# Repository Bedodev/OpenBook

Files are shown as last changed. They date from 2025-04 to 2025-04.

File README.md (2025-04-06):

# OpenBook
OpenBook is an open Source eBook Project that aims to create a simple yet powerful esp32-based ebook reader, with quality of life features. 

## Block Diagram
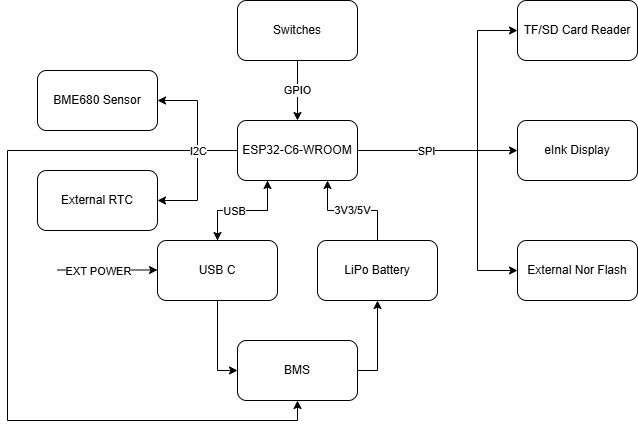
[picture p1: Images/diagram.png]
block-diagram


## Simplified BoM
Component | Part # | Source Link
--- | --- | ---
ESP32 | ESP32-C6-WROOM-1-N8 | [Mouser](https://mou.sr/42swLfH)
MicroSD Card Reader | 112A-TAAR-R03 | [DigiKey](https://www.digikey.ro/en/models/17633923)
NOR Flash | W25Q512JVEIQ | [ComponentSearchengine](https://componentsearchengine.com/search?term=W25Q512JVEIQ)
Adafruit Led | SM0603UYC | [SnapEda](https://www.snapeda.com/parts/SM0603UYC/Bivar/view-part/)
Environment Sensor | BME680 | [DigiKey](https://www.digikey.lt/en/models/7401317)
Super Capacitor | CPH3225A-2K | [SnapMagic](https://www.snapeda.com/parts/CPH3225A-2K/Seiko/view-part/)
0402 capsule | RC0402 | [GrabCad](https://grabcad.com/library/tag/0402)
Tantalum Capacitor | TR3B106K025C1300 | [Mouser](https://eu.mouser.com/ProductDetail/Vishay-Sprague/TR3B106K025C1300?qs=jCGqFXxTmLdffnuDkXzk1g%3D%3D)
RTC | DS3231SN# | [ComponentSearchEngine](https://componentsearchengine.com/part-view/DS3231SN%23/Analog%20Devices)
Voltage Detector | BD5229G-TR | [ComponentSearchEngine](https://componentsearchengine.com/part-view/BD5229G-TR/ROHM%20Semiconductor)
Right Angle Switches | EVQ-P7M01P | [Mouser](https://mou.sr/41Z13GK)
Inductor | 784373170680 | [DigiKey](https://www.digikey.ro/en/models/1638502)
Varsistor | CT1812K50G | [ComponentSearchEngine](https://componentsearchengine.com/part-view/CT1812K50G/TDK)
Schottky Diode | SD0805S020S1R0 | [ComponentSearchEngine](https://componentsearchengine.com/part-view/SD0805S020S1R0/Kyocera%20AVX)
Schotty Rectifier | MBR0530 | [ComponentSearchEngine](https://componentsearchengine.com/part-view/MBR0530/onsemi)
ESD Protection | USBLC6-2SC6Y | [ComponentSearchEngine](https://componentsearchengine.com/part-view/USBLC6-2SC6Y/STMicroelectronics)
ESD Suppressors | PGB1010603MR | [ComponentSearchEngine](https://componentsearchengine.com/part-view/PGB1010603MR/LITTELFUSE)
N-MOSFET | Si1308EDL-T1-GE3 | [ComponentSearchEngine](https://componentsearchengine.com/part-view/SI1308EDL-T1-GE3/Vishay)
Qwiic Connector | PRT-14417 | [ComponentSearchEngine](https://componentsearchengine.com/part-view/PRT-14417/SparkFun)
USB Connector | USB4110-GF-A | [ComponentSearchEngine](https://componentsearchengine.com/part-view/USB4110-GF-A/GCT%20(GLOBAL%20CONNECTOR%20TECHNOLOGY))
Display Connector | FH34SRJ-24S-0.5SH(99) | [ComponentSearchEngine](https://componentsearchengine.com/part-view/FH34SRJ-24S-0.5SH(99)/Hirose)
Battery Percentage Chip | MAX17048G+T10 | [ComponentSearchEngine](https://componentsearchengine.com/part-view/MAX17048G%2BT10/Analog%20Devices)
Voltage Reculator | XC6220A331MR-G | [ComponentSearchEngine](https://componentsearchengine.com/part-view/XC6220A331MR-G/Torex)
LiPo Controller | HT7750A | [ComponentSearchengine](https://componentsearchengine.com/part-view/HT7750A%20SOT23-3/Holtek)

## Hardware Overview
  -  **ESP32-C6**: energy efficient RISC based mcu, with wireless connectivity for easy ebook content access and transfer
  -  **eInk Display**: energy efficient black and white display with paper-like look
  -  **Usb-C Port**: easy charging and connectivity with esd protection
  -  **SdCard Reader**: user-accessible expandable storage
  -  **External Flash**: built-in storage for basic functionality
  -  **Real Time Clock**: maintains time data on power off
  -  **Environmental Sensor**: high-accuracy environment data collection for safe usage warnings
  -  **Qwiic Connector**: allows future expandability
  -  **Side Switches**: simple user interfacing with device operations

## ESP32 Pin Mapping
 1. **USB**: user charging and data access
    - IO12 - Usb Data-
    - IO13 - Usb Data+
 2. **GPIO**: user interfacing
    - EN - reset switch, for easy access to chip reset
    - IO9 - "change" switch, for display mode switch
    - IO15 - boot switch, for device startup and shutdown
 2. **SPI**: display, sd card, flash
    - IO2 - MISO, master in slave out, used for data transfer from chip to esp
    - IO7 - MOSI, master out slave in, used for data transfer from esp to chip
    - IO6 - SCK, clock bus sync between esp and chip
    - IO5 - DC, data/command
    - IO3 - busy, for signaling device cannot receive command
 2. **I2C**: battery monitoring, rtc, environment sensing
    - IO21 - SDA, bidirectional serial data line
    - IO22 - SCL, bidirectional serial clock line

## Other comments
 - DRC warnings for the usb allignment pins have to be manually approved
 - Inductor 3D model different from BoM component, but, for development and showcase purposes, footprint and 3D model fit the original

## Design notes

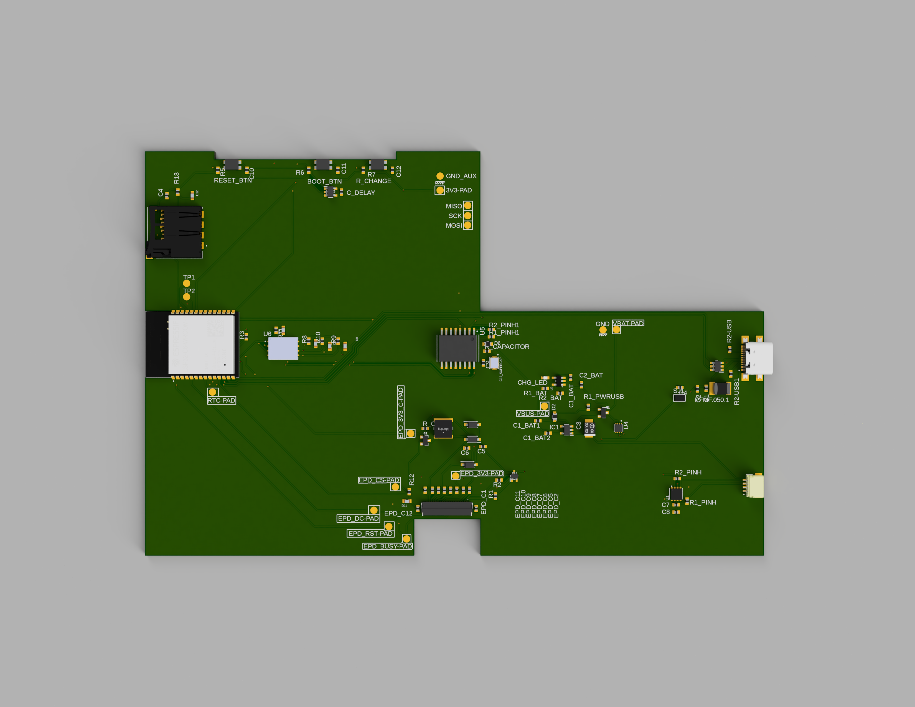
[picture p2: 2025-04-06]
Images/pcb_3d_front.png

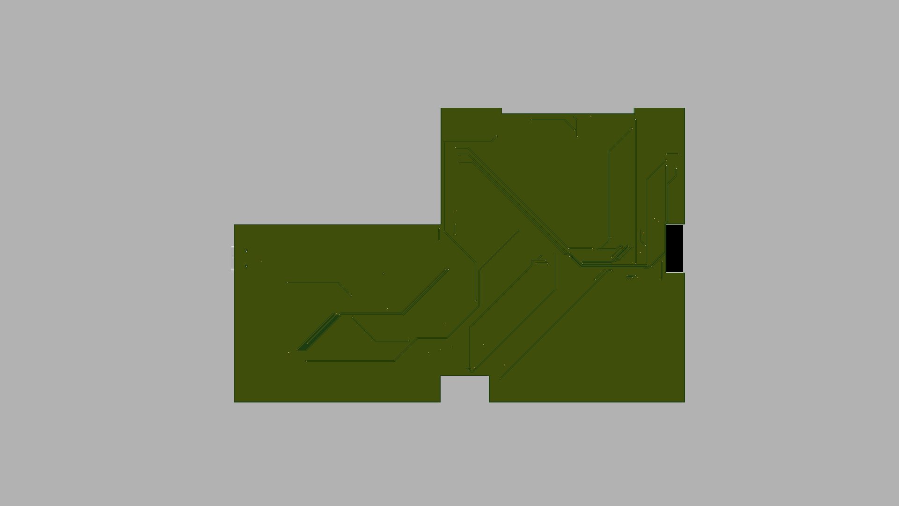
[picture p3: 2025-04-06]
Images/pcb_3d_back.png

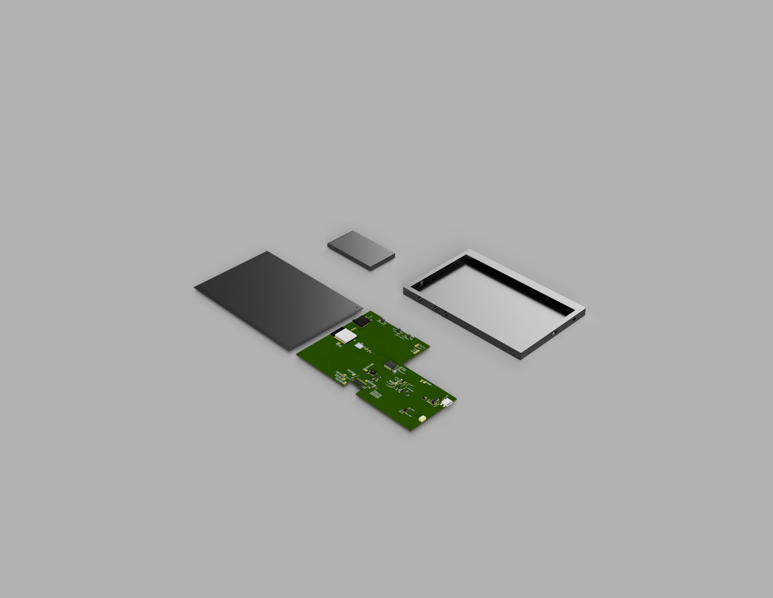
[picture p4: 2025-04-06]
Images/exploded_flat.png

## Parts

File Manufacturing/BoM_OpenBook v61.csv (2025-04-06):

Part | Value | Device | Package | Description
3V3-PAD | TPTP20R | TPTP20R | TP20R | Test pad
BOOT_BTN | BUTTON_CUSYOMV1 | BUTTON_CUSYOMV1 | MYBUTTON
C1 | 100nF | ESP32_WROVER_EAGLE-LTSPICE_CC0402 | ESP32_WROVER_EAGLE-LTSPICE_C0402 | CAPACITOR, European symbol
C1_BAT | 4.7uF | EAGLE-LTSPICE_CC0402 | EAGLE-LTSPICE_C0402 | CAPACITOR, European symbol
C1_BAT1 | 4.7uF | EAGLE-LTSPICE_CC0402 | EAGLE-LTSPICE_C0402 | CAPACITOR, European symbol
C1_BAT2 | 4.7uF | EAGLE-LTSPICE_CC0402 | EAGLE-LTSPICE_C0402 | CAPACITOR, European symbol
C2 | 100nF | ESP32_WROVER_EAGLE-LTSPICE_CC0402 | ESP32_WROVER_EAGLE-LTSPICE_C0402 | CAPACITOR, European symbol
C2_BAT | 4.7uF | EAGLE-LTSPICE_CC0402 | EAGLE-LTSPICE_C0402 | CAPACITOR, European symbol
C3 | 100uF TANT | RCL_CPOL-EUCT3528 | RCL_CT3528 | POLARIZED CAPACITOR, European symbol
C4 | 100nF | EAGLE-LTSPICE_CC0402 | EAGLE-LTSPICE_C0402 | CAPACITOR, European symbol
C5 | 4.7uF/25V | ESP32_WROVER_EAGLE-LTSPICE_CC0402 | ESP32_WROVER_EAGLE-LTSPICE_C0402 | CAPACITOR, European symbol
C6 | 10uF | ESP32_WROVER_EAGLE-LTSPICE_CC0402 | ESP32_WROVER_EAGLE-LTSPICE_C0402 | CAPACITOR, European symbol
C7 | 100nF | EAGLE-LTSPICE_CC0402 | EAGLE-LTSPICE_C0402 | CAPACITOR, European symbol
C8 | 100nF | EAGLE-LTSPICE_CC0402 | EAGLE-LTSPICE_C0402 | CAPACITOR, European symbol
C9 | 100nF | EAGLE-LTSPICE_CC0402 | EAGLE-LTSPICE_C0402 | CAPACITOR, European symbol
C10 | 1uF | EAGLE-LTSPICE_CC0402 | EAGLE-LTSPICE_C0402 | CAPACITOR, European symbol
C11 | 100nF | EAGLE-LTSPICE_CC0402 | EAGLE-LTSPICE_C0402 | CAPACITOR, European symbol
C12 | 100nF | EAGLE-LTSPICE_CC0402 | EAGLE-LTSPICE_C0402 | CAPACITOR, European symbol
C13_SUPERCAP | CPH3225A | CPH3225A | CAPCP3225X100N | Cap 0.011F 3.3V 1210 Flat Check availability
CHG_LED |  | ADAFRUIT_LEDCHIP-LED0603 | ADAFRUIT_CHIP-LED0603 | LED
C_DELAY | 100nF | EAGLE-LTSPICE_CC0402 | EAGLE-LTSPICE_C0402 | CAPACITOR, European symbol
D1 | USBLC6-2SC6Y | USBLC6-2SC6Y | SOT95P280X145-6N | Low Cap. ESD Protection Auto SOT-23-6 STMicroelectronics USBLC6-2SC6Y, Dual Uni-Directional TVS Diode Array, 6-Pin SOT-23
D2 | ESP32_WROVER_AVX---SD0805S020S1R0_AVX_SD0805S020S1R0_0_0AVX_SD0805S020S1R0_0_0 | ESP32_WROVER_AVX---SD0805S020S1R0_AVX_SD0805S020S1R0_0_0AVX_SD0805S020S1R0_0_0 | ESP32_WROVER_AVX---SD0805S020S1R0_AVX_SD0805S020S1R0_0 | Schottky Barrier Rectifier Diode
D3 | MBR0530 | MBR0530 | SOD3716X135N | ON SEMICONDUCTOR - MBR0530 - DIODE, SCHOTTKY, 0.5A, 30V, SOD-123
D4 | MBR0530 | MBR0530 | SOD3716X135N | ON SEMICONDUCTOR - MBR0530 - DIODE, SCHOTTKY, 0.5A, 30V, SOD-123
D5 | MBR0530 | MBR0530 | SOD3716X135N | ON SEMICONDUCTOR - MBR0530 - DIODE, SCHOTTKY, 0.5A, 30V, SOD-123
D6 | ESP32_WROVER_AVX---SD0805S020S1R0_AVX_SD0805S020S1R0_0_0AVX_SD0805S020S1R0_0_0 | ESP32_WROVER_AVX---SD0805S020S1R0_AVX_SD0805S020S1R0_0_0AVX_SD0805S020S1R0_0_0 | ESP32_WROVER_AVX---SD0805S020S1R0_AVX_SD0805S020S1R0_0 | Schottky Barrier Rectifier Diode
D7 | PGB1010603MR | PGB1010603MR | DIOC1608X36N | Check availability
D8 | PGB1010603MR | PGB1010603MR | DIOC1608X36N | Check availability
D9 | PGB1010603MR | PGB1010603MR | DIOC1608X36N | Check availability
D10 | PGB1010603MR | PGB1010603MR | DIOC1608X36N | Check availability
D11 | PGB1010603MR | PGB1010603MR | DIOC1608X36N | Check availability
D12 | PGB1010603MR | PGB1010603MR | DIOC1608X36N | Check availability
EPD_3V3-PAD | TPTP20R | TPTP20R | TP20R | Test pad
EPD_3V3_C-PAD | TPTP20R | TPTP20R | TP20R | Test pad
EPD_BUSY-PAD | TPTP20R | TPTP20R | TP20R | Test pad
EPD_C1 | 1uF/50V | ESP32_WROVER_EAGLE-LTSPICE_CC0402 | ESP32_WROVER_EAGLE-LTSPICE_C0402 | CAPACITOR, European symbol
EPD_C2 | 1uF/50V | ESP32_WROVER_EAGLE-LTSPICE_CC0402 | ESP32_WROVER_EAGLE-LTSPICE_C0402 | CAPACITOR, European symbol
EPD_C5 | 0.1uF/50V | ESP32_WROVER_EAGLE-LTSPICE_CC0402 | ESP32_WROVER_EAGLE-LTSPICE_C0402 | CAPACITOR, European symbol
EPD_C6 | 1uF/50V | ESP32_WROVER_EAGLE-LTSPICE_CC0402 | ESP32_WROVER_EAGLE-LTSPICE_C0402 | CAPACITOR, European symbol
EPD_C7 | 1uF/50V | ESP32_WROVER_EAGLE-LTSPICE_CC0402 | ESP32_WROVER_EAGLE-LTSPICE_C0402 | CAPACITOR, European symbol
EPD_C8 | 1uF/50V | ESP32_WROVER_EAGLE-LTSPICE_CC0402 | ESP32_WROVER_EAGLE-LTSPICE_C0402 | CAPACITOR, European symbol
EPD_C9 | 1uF/50V | ESP32_WROVER_EAGLE-LTSPICE_CC0402 | ESP32_WROVER_EAGLE-LTSPICE_C0402 | CAPACITOR, European symbol
EPD_C10 | 1uF/50V | ESP32_WROVER_EAGLE-LTSPICE_CC0402 | ESP32_WROVER_EAGLE-LTSPICE_C0402 | CAPACITOR, European symbol
EPD_C11 | 1uF/50V | ESP32_WROVER_EAGLE-LTSPICE_CC0402 | ESP32_WROVER_EAGLE-LTSPICE_C0402 | CAPACITOR, European symbol
EPD_C12 | 1uF/50V | ESP32_WROVER_EAGLE-LTSPICE_CC0402 | ESP32_WROVER_EAGLE-LTSPICE_C0402 | CAPACITOR, European symbol
EPD_CS-PAD | TPTP20R | TPTP20R | TP20R | Test pad
EPD_DC-PAD | TPTP20R | TPTP20R | TP20R | Test pad
EPD_RST-PAD | TPTP20R | TPTP20R | TP20R | Test pad
GND | TPTP20R | TPTP20R | TP20R | Test pad
GND_AUX | TPTP20R | TPTP20R | TP20R | Test pad
IC1 | XC6220A331MR-G | XC6220A331MR-G | SOT95P280X120-5N | LDO Voltage Regulators
IC2 | BD5229G-TR | BD5229G-TR | SOT95P280X125-5N | Voltage Detector with Adjustable Delay Time: CMOS processes are utilized to develop high precision, low current consumption CMOS reset ICs that allow arbitrary setting of the delay time. The extensive lineup includes both Nch Open Drain and CMOS output types in a wide range of detection voltages (from 2.3V to 6.0V, in 0.1V steps), enabling selection of the ideal solution based on customer requirements. In addition, the entire series is of course both lead-free and RoHS-compliant.
J1 | SAMACSYS_PARTS_USB4110-GF-A | SAMACSYS_PARTS_USB4110-GF-A | SAMACSYS_PARTS_USB4110GFA | CONN USB 2.0 TYPE-C R/A SMT
J2 | 112A-TAAR-R03_ATTEND | 112A-TAAR-R03_ATTEND | 112ATAARR03ATTEND | Micro SD Card Socket, Push-Push Type, Top Mount, SMT, H=1.83mm, 10u
J3 | FH34SRJ-24S-0.5SH_99_ | FH34SRJ-24S-0.5SH_99_ | FH34SRJ24S05SH99 | (0.50mm) Surface Mount, Right Angle
J4 | QWIIC_RIGHT_ANGLE | QWIIC_CONNECTORJS-1MM | JST04_1MM_RA | SparkFun I2C Standard Qwiic Connector
L1 | 68uH | 744043680IND_4828-WE-TPC_WRE | IND_4828-WE-TPC_WRE
MISO | TPTP20R | TPTP20R | TP20R | Test pad
MOSI | TPTP20R | TPTP20R | TP20R | Test pad
PFMF.050.1 | PFMF.050.1 | ESP32C6_VARISTORCN1812 | ESP32C6_VARISTOR_CT/CN1812 | VARISTOR
Q1 | 20V/4.2A/52mO/1.4W | ESP32_WROVER_SPARKFUN-DISCRETESEMI_MOSFET_PCH-DMG2305UX-7 | ESP32_WROVER_SPARKFUN-DISCRETESEMI_SOT23-3 | P-channel MOSFETs
Q2 | SI1308EDL-T1-GE3 | SI1308EDL-T1-GE3 | SOT65P210X110-3N | MOSFET N-Ch 30V 1.5A TrenchFET SC70 Vishay Si1308EDL-T1-GE3 N-channel MOSFET Transistor, 1.5 A, 30 V, 3-Pin SC-70
Q3 | 20V/4.2A/52mO/1.4W | ESP32_WROVER_SPARKFUN-DISCRETESEMI_MOSFET_PCH-DMG2305UX-7 | ESP32_WROVER_SPARKFUN-DISCRETESEMI_SOT23-3 | P-channel MOSFETs
R1 | 10K | ESP32_WROVER_EAGLE-LTSPICE_RR0402 | ESP32_WROVER_EAGLE-LTSPICE_R0402 | RESISTOR, European symbol
R1_BAT | 200 | ESP32_WROVER_EAGLE-LTSPICE_RR0402 | ESP32_WROVER_EAGLE-LTSPICE_R0402 | RESISTOR, European symbol
R1_PINH | 10K | ESP32_WROVER_EAGLE-LTSPICE_RR0402 | ESP32_WROVER_EAGLE-LTSPICE_R0402 | RESISTOR, European symbol
R1_PINH1 | 10K | ESP32_WROVER_EAGLE-LTSPICE_RR0402 | ESP32_WROVER_EAGLE-LTSPICE_R0402 | RESISTOR, European symbol
R1_PWRUSB | 100K | ESP32_WROVER_EAGLE-LTSPICE_RR0402 | ESP32_WROVER_EAGLE-LTSPICE_R0402 | RESISTOR, European symbol
R2 | 0.47 | ESP32_WROVER_EAGLE-LTSPICE_RR0402 | ESP32_WROVER_EAGLE-LTSPICE_R0402 | RESISTOR, European symbol
R2-USB | 5k1 | ESP32_WROVER_EAGLE-LTSPICE_RR0402 | ESP32_WROVER_EAGLE-LTSPICE_R0402 | RESISTOR, European symbol
R2-USB1 | 5k1 | ESP32_WROVER_EAGLE-LTSPICE_RR0402 | ESP32_WROVER_EAGLE-LTSPICE_R0402 | RESISTOR, European symbol
R2_BAT | 2K | ESP32_WROVER_EAGLE-LTSPICE_RR0402 | ESP32_WROVER_EAGLE-LTSPICE_R0402 | RESISTOR, European symbol
R2_PINH | 10K | ESP32_WROVER_EAGLE-LTSPICE_RR0402 | ESP32_WROVER_EAGLE-LTSPICE_R0402 | RESISTOR, European symbol
R2_PINH1 | 10K | ESP32_WROVER_EAGLE-LTSPICE_RR0402 | ESP32_WROVER_EAGLE-LTSPICE_R0402 | RESISTOR, European symbol
R3 | 10K | ESP32_WROVER_EAGLE-LTSPICE_RR0402 | ESP32_WROVER_EAGLE-LTSPICE_R0402 | RESISTOR, European symbol
R4 | 2.2 | ESP32_WROVER_EAGLE-LTSPICE_RR0402 | ESP32_WROVER_EAGLE-LTSPICE_R0402 | RESISTOR, European symbol
R5 |  | ESP32_WROVER_EAGLE-LTSPICE_RR0402 | ESP32_WROVER_EAGLE-LTSPICE_R0402 | RESISTOR, European symbol
R6 |  | ESP32_WROVER_EAGLE-LTSPICE_RR0402 | ESP32_WROVER_EAGLE-LTSPICE_R0402 | RESISTOR, European symbol
R7 |  | ESP32_WROVER_EAGLE-LTSPICE_RR0402 | ESP32_WROVER_EAGLE-LTSPICE_R0402 | RESISTOR, European symbol
R8 | 10K | ESP32_WROVER_EAGLE-LTSPICE_RR0402 | ESP32_WROVER_EAGLE-LTSPICE_R0402 | RESISTOR, European symbol
R9 | 10K | ESP32_WROVER_EAGLE-LTSPICE_RR0402 | ESP32_WROVER_EAGLE-LTSPICE_R0402 | RESISTOR, European symbol
R10 | 10K | ESP32_WROVER_EAGLE-LTSPICE_RR0402 | ESP32_WROVER_EAGLE-LTSPICE_R0402 | RESISTOR, European symbol
R11 | 10K | ESP32_WROVER_EAGLE-LTSPICE_RR0402 | ESP32_WROVER_EAGLE-LTSPICE_R0402 | RESISTOR, European symbol
R12 | 10K | ESP32_WROVER_EAGLE-LTSPICE_RR0402 | ESP32_WROVER_EAGLE-LTSPICE_R0402 | RESISTOR, European symbol
R13 | 10K | ESP32_WROVER_EAGLE-LTSPICE_RR0402 | ESP32_WROVER_EAGLE-LTSPICE_R0402 | RESISTOR, European symbol
RESET_BTN | BUTTON_CUSYOMV1 | BUTTON_CUSYOMV1 | MYBUTTON
RTC-PAD | TPTP20R | TPTP20R | TP20R | Test pad
R_CAPACITOR |  | ESP32_WROVER_EAGLE-LTSPICE_RR0402 | ESP32_WROVER_EAGLE-LTSPICE_R0402 | RESISTOR, European symbol
R_CHANGE | BUTTON_CUSYOMV1 | BUTTON_CUSYOMV1 | MYBUTTON
R_CL1 | 10K | ESP32_WROVER_EAGLE-LTSPICE_RR0402 | ESP32_WROVER_EAGLE-LTSPICE_R0402 | RESISTOR, European symbol
SCK | TPTP20R | TPTP20R | TP20R | Test pad
SJ1 |  | SJ | SJ | SMD solder JUMPER
TP1 | TPTP20R | TPTP20R | TP20R | Test pad
TP2 | TPTP20R | TPTP20R | TP20R | Test pad
U1 | BME688 | ESP32_WROVER_BME680_BME680 | ESP32_WROVER_BME680_PSON80P300X300X100-8N | Integrated Environmental Unit
U2 | MCP73831 | ESP32_WROVER_SPARKFUN-IC-POWER_MCP73831 | ESP32_WROVER_SPARKFUN-IC-POWER_SOT23-5 | MCP73831T Li-Ion, Li-Pol Controller
U3 | ESP32-C6-WROOM-1-N8 | ESP32-C6-WROOM-1-N8 | XCVR_ESP32-C6-WROOM-1-N8 | Check availability
U4 | MAX17048G+T10 | MAX17048G+T10 | SON50P200X200X80-9N | Check availability
U5 | DS3231SN# | DS3231SN# | SOIC127P1032X265-16N | Real Time Clock Serial 16-Pin SOIC W T/R Check availability
U6 | W25Q512JVEIQ | W25Q512JVEIQ | SON127P600X800X80-9N | Check availability
VBAT-PAD | TPTP20R | TPTP20R | TP20R | Test pad
VBUS-PAD | TPTP20R | TPTP20R | TP20R | Test pad

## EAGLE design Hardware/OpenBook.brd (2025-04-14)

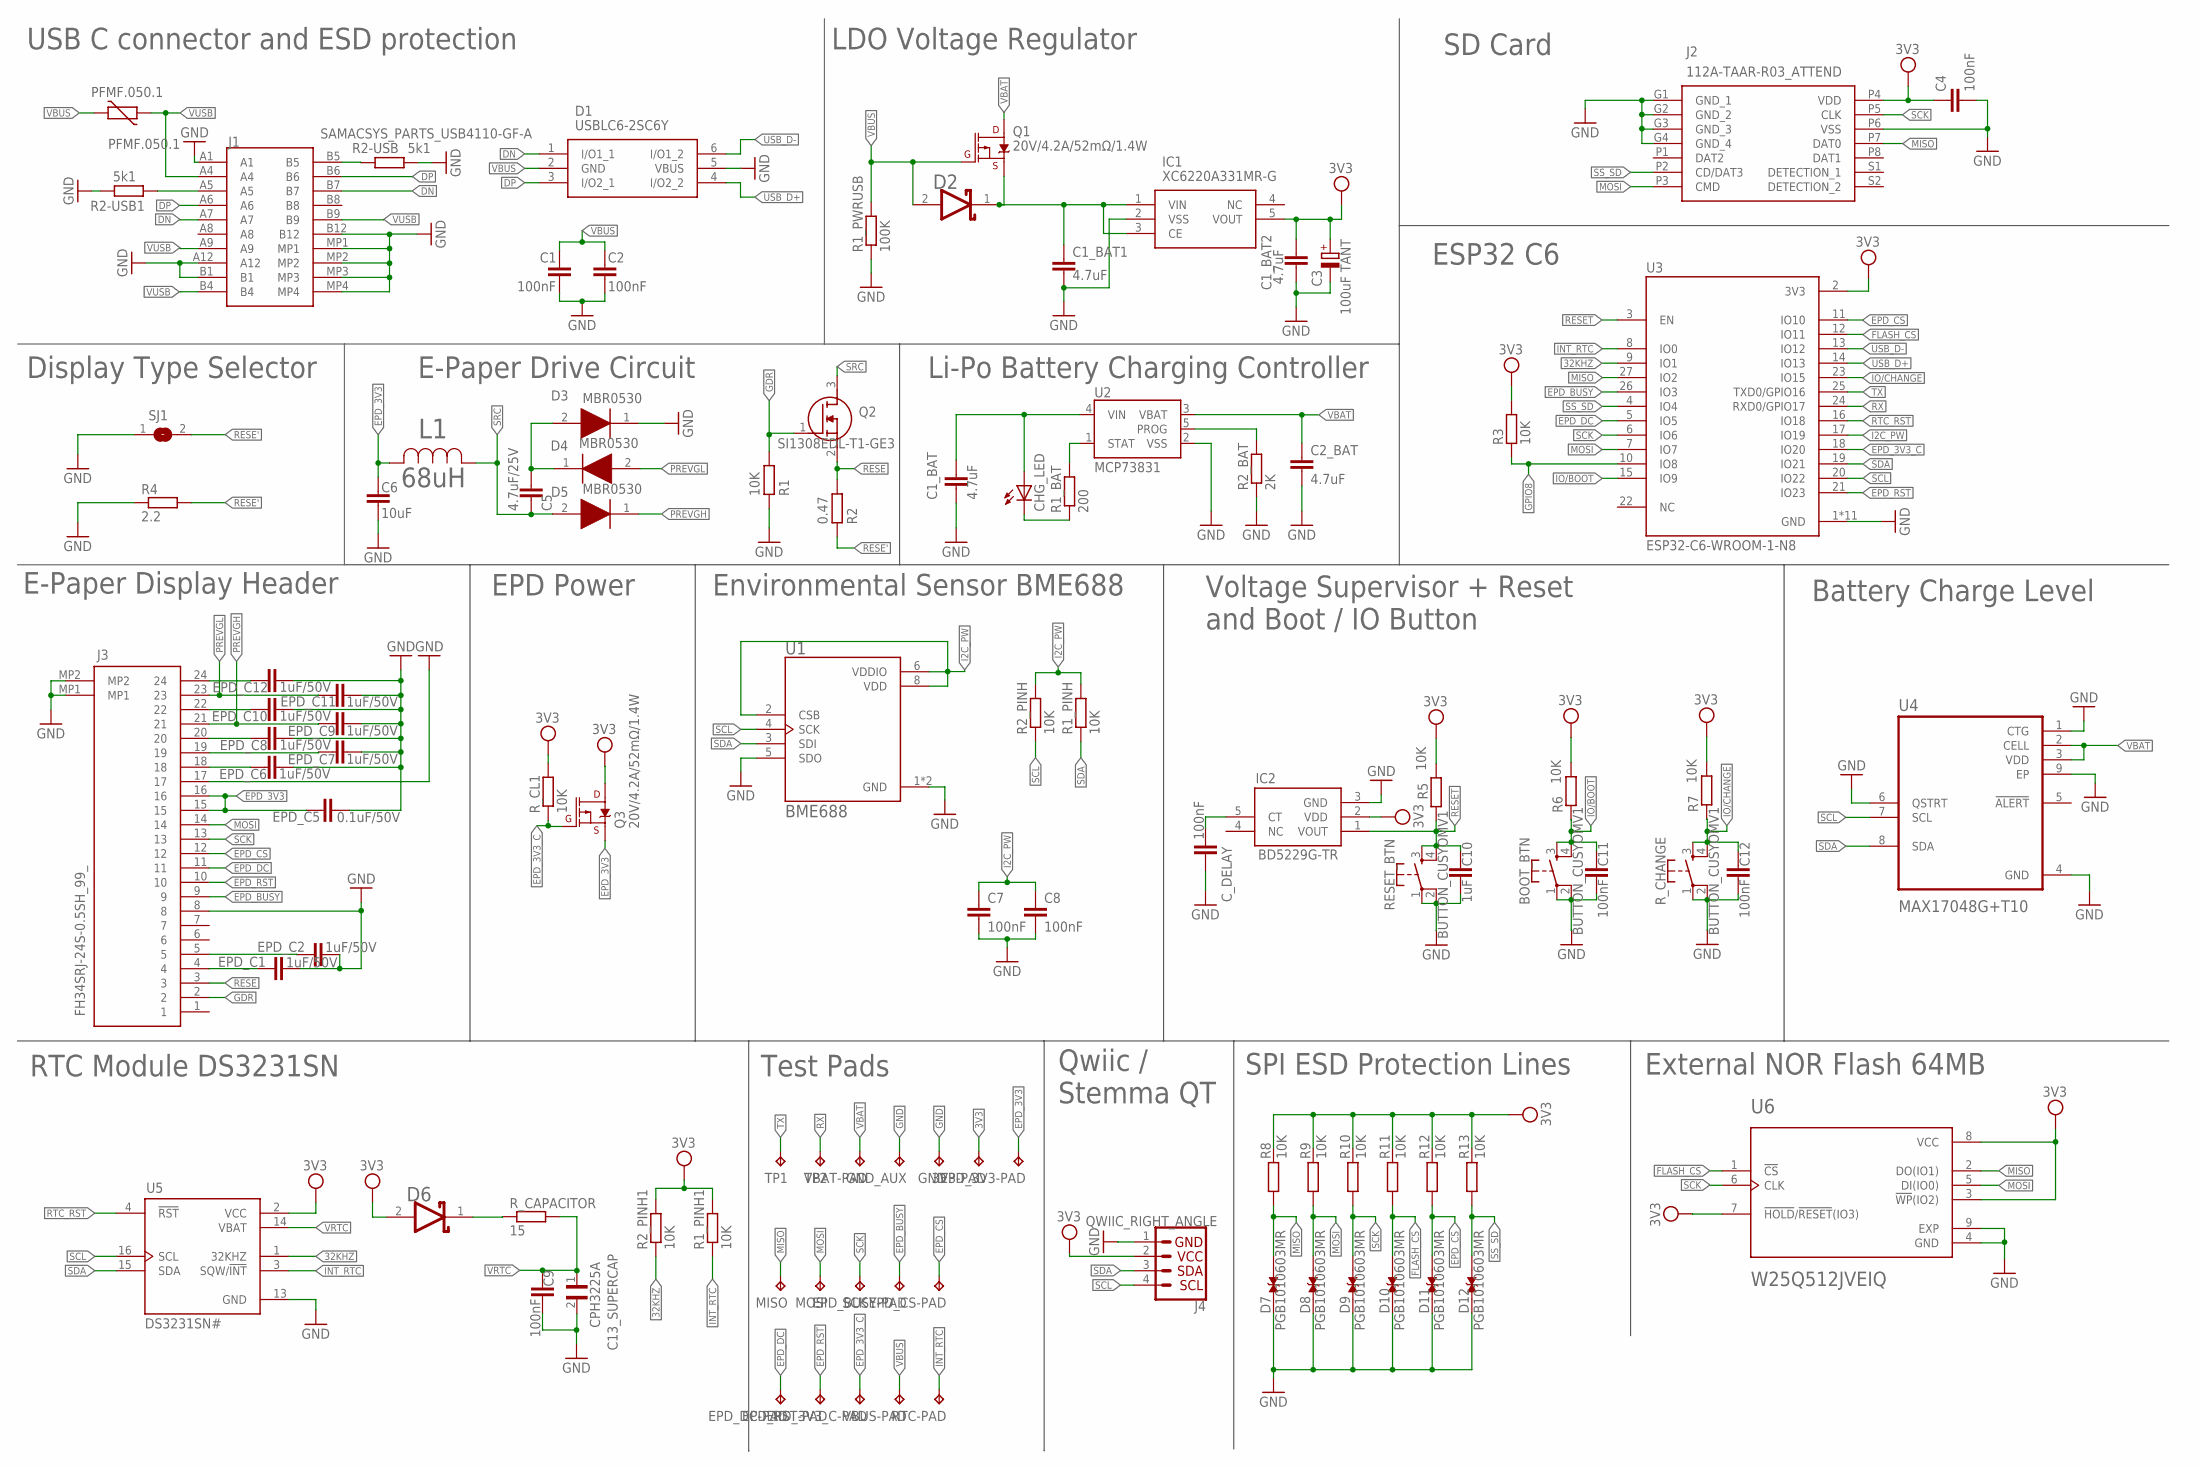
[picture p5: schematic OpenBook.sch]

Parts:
3V3-PAD: TPTP20R; TP20R
BOOT_BTN: BUTTON_CUSYOMV1; MYBUTTON
C1, C2: 100nF; ESP32_WROVER_EAGLE-LTSPICE_C0402
C1_BAT, C1_BAT1, C1_BAT2, C2_BAT: 4.7uF; EAGLE-LTSPICE_C0402
C3: 100uF TANT; RCL_CT3528
C4, C7, C8, C9, C11, C12: 100nF; EAGLE-LTSPICE_C0402
C5: 4.7uF/25V; ESP32_WROVER_EAGLE-LTSPICE_C0402
C6: 10uF; ESP32_WROVER_EAGLE-LTSPICE_C0402
C10: 1uF; EAGLE-LTSPICE_C0402
C13_SUPERCAP: CPH3225A; CAPCP3225X100N
CHG_LED: ADAFRUIT_LEDCHIP-LED0603; ADAFRUIT_CHIP-LED0603
C_DELAY: 100nF; EAGLE-LTSPICE_C0402
D1: USBLC6-2SC6Y; SOT95P280X145-6N
D2, D6: ESP32_WROVER_AVX---SD0805S020S1R0_AVX_SD0805S020S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; ESP32_WROVER_AVX---SD0805S020S1R0_AVX_SD0805S020S1R0_0
D3, D4, D5: MBR0530; SOD3716X135N
D7, D8, D9, D10, D11, D12: PGB1010603MR; DIOC1608X36N
EPD_3V3-PAD, EPD_3V3_C-PAD: TPTP20R; TP20R
EPD_BUSY-PAD: TPTP20R; TP20R
EPD_C1, EPD_C2, EPD_C6, EPD_C7, EPD_C8, EPD_C9, EPD_C10, EPD_C11, EPD_C12: 1uF/50V; ESP32_WROVER_EAGLE-LTSPICE_C0402
EPD_C5: 0.1uF/50V; ESP32_WROVER_EAGLE-LTSPICE_C0402
EPD_CS-PAD: TPTP20R; TP20R
EPD_DC-PAD: TPTP20R; TP20R
EPD_RST-PAD: TPTP20R; TP20R
GND: TPTP20R; TP20R
GND_AUX: TPTP20R; TP20R
IC1: XC6220A331MR-G; SOT95P280X120-5N
IC2: BD5229G-TR; SOT95P280X125-5N
J1: SAMACSYS_PARTS_USB4110-GF-A; SAMACSYS_PARTS_USB4110GFA
J2: 112A-TAAR-R03_ATTEND; 112ATAARR03ATTEND
J3: FH34SRJ-24S-0.5SH_99_; FH34SRJ24S05SH99
J4: QWIIC_RIGHT_ANGLE; JST04_1MM_RA
L1: 68uH; IND_4828-WE-TPC_WRE
MISO: TPTP20R; TP20R
MOSI: TPTP20R; TP20R
PFMF.050.1: PFMF.050.1; ESP32C6_VARISTOR_CT/CN1812
Q1, Q3: 20V/4.2A/52mΩ/1.4W; ESP32_WROVER_SPARKFUN-DISCRETESEMI_SOT23-3
Q2: SI1308EDL-T1-GE3; SOT65P210X110-3N
R1, R1_PINH, R1_PINH1, R2_PINH, R2_PINH1, R3, R5, R6, R7, R8, R9, R10, R11, R12, R13: 10K; ESP32_WROVER_EAGLE-LTSPICE_R0402
R1_BAT: 200; ESP32_WROVER_EAGLE-LTSPICE_R0402
R1_PWRUSB: 100K; ESP32_WROVER_EAGLE-LTSPICE_R0402
R2: 0.47; ESP32_WROVER_EAGLE-LTSPICE_R0402
R2-USB, R2-USB1: 5k1; ESP32_WROVER_EAGLE-LTSPICE_R0402
R2_BAT: 2K; ESP32_WROVER_EAGLE-LTSPICE_R0402
R4: 2.2; ESP32_WROVER_EAGLE-LTSPICE_R0402
RESET_BTN: BUTTON_CUSYOMV1; MYBUTTON
RTC-PAD: TPTP20R; TP20R
R_CAPACITOR: 15; ESP32_WROVER_EAGLE-LTSPICE_R0402
R_CHANGE: BUTTON_CUSYOMV1; MYBUTTON
R_CL1: 10K; ESP32_WROVER_EAGLE-LTSPICE_R0402
SCK: TPTP20R; TP20R
SJ1: SJ
TP1, TP2: TPTP20R; TP20R
U1: BME688; ESP32_WROVER_BME680_PSON80P300X300X100-8N
U2: MCP73831; ESP32_WROVER_SPARKFUN-IC-POWER_SOT23-5
U3: ESP32-C6-WROOM-1-N8; XCVR_ESP32-C6-WROOM-1-N8
U4: MAX17048G+T10; SON50P200X200X80-9N
U5: DS3231SN#; SOIC127P1032X265-16N
U6: W25Q512JVEIQ; SON127P600X800X80-9N
VBAT-PAD: TPTP20R; TP20R
VBUS-PAD: TPTP20R; TP20R

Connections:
3V3: 3V3-PAD.TP, C1_BAT2.1, C3.+, C4.1, D6.2 (ANODE), IC1.5 (VOUT), IC2.2 (VDD), J2.P4 (VDD), J4.2, Q3.3 (D), R1_PINH1.2, R2_PINH1.2, R3.2, R5.2, R6.2, R7.2, R8.2, R9.2, R10.2, R11.2, R12.2, R13.2, R_CL1.2, U3.2 (3V3), U5.2 (VCC), U6.3 (!WP!(IO2)), U6.7 (!HOLD!/!RESET!(IO3)), U6.8 (VCC)
32KHZ: R2_PINH1.1, U3.9 (IO1), U5.1 (32KHZ)
DN: D1.1 (I/O1_1), J1.A7, J1.B7
DP: D1.3 (I/O2_1), J1.A6, J1.B6
EPD_3V3: C6.1, EPD_3V3-PAD.TP, EPD_C5.1, J3.15, J3.16, L1.2, Q3.2 (S)
EPD_3V3_C: EPD_3V3_C-PAD.TP, Q3.1 (G), R_CL1.1, U3.18 (IO20)
EPD_BUSY: EPD_BUSY-PAD.TP, J3.9, U3.26 (IO3)
EPD_CS: D11.2, EPD_CS-PAD.TP, J3.12, R12.1, U3.11 (IO10)
EPD_DC: EPD_DC-PAD.TP, J3.11, U3.5 (IO5)
EPD_RST: EPD_RST-PAD.TP, J3.10, U3.21 (IO23)
FLASH_CS: D10.2, R11.1, U3.12 (IO11), U6.1 (!CS)
GDR: J3.2, Q2.1 (G), R1.2
GND: BOOT_BTN.1, BOOT_BTN.2, C1.2, C1_BAT.2, C1_BAT1.2, C1_BAT2.2, C2.2, C2_BAT.2, C3.-, C4.2, C6.2, C7.2, C8.2, C9.2, C10.2, C11.2, C12.2, C13_SUPERCAP.2, C_DELAY.2, D1.5 (VBUS), D3.1 (K), D7.1, D8.1, D9.1, D10.1, D11.1, D12.1, EPD_C1.1, EPD_C2.1, EPD_C5.2, EPD_C6.2, EPD_C7.2, EPD_C8.2, EPD_C9.2, EPD_C10.2, EPD_C11.2, EPD_C12.2, GND.TP, GND_AUX.TP, IC1.2 (VSS), IC2.3 (GND), J1.A1, J1.A12, J1.B1, J1.B12, J1.MP1, J1.MP2, J1.MP3, J1.MP4, J2.G1 (GND_1), J2.G2 (GND_2), J2.G3 (GND_3), J2.G4 (GND_4), J2.P6 (VSS), J3.8, J3.17, J3.MP1, J3.MP2, J4.1, R1.1, R1_PWRUSB.1, R2-USB.2, R2-USB1.1, R2_BAT.1, R4.1, RESET_BTN.1, RESET_BTN.2, R_CHANGE.1, R_CHANGE.2, SJ1.1, U1.1 (GND), U1.5 (SDO), U1.7 (GND), U2.2 (VSS), U3.1 (GND), U3.28 (GND), U3.29_1 (GND), U3.29_2 (GND), U3.29_3 (GND), U3.29_4 (GND), U3.29_5 (GND), U3.29_6 (GND), U3.29_7 (GND), U3.29_8 (GND), U3.29_9 (GND), U4.1 (CTG), U4.4 (GND), U4.6 (QSTRT), U4.9 (EP), U5.13 (GND), U6.4 (GND), U6.9 (EXP)
GPIO8: R3.1, U3.10 (IO8)
I2C_PW: C7.1, C8.1, R1_PINH.2, R2_PINH.2, U1.2 (CSB), U1.6 (VDDIO), U1.8 (VDD), U3.17 (IO19)
INT_RTC: R1_PINH1.1, RTC-PAD.TP, U3.8 (IO0), U5.3 (SQW/!INT)
IO/BOOT: BOOT_BTN.3, BOOT_BTN.4, C11.1, R6.1, U3.15 (IO9)
IO/CHANGE: C12.1, R7.1, R_CHANGE.3, R_CHANGE.4, U3.23 (IO15)
MISO: D7.2, J2.P7 (DAT0), MISO.TP, R8.1, U3.27 (IO2), U6.2 (DO(IO1))
MOSI: D8.2, J2.P3 (CMD), J3.14, MOSI.TP, R9.1, U3.7 (IO7), U6.5 (DI(IO0))
unnamed: J1.A5, R2-USB1.2
unnamed: J1.B5, R2-USB.1
unnamed: C1_BAT1.1, D2.1 (CATHODE), IC1.1 (VIN), IC1.3 (CE), Q1.2 (S)
unnamed: C5.1, D3.2 (A), D4.1 (K)
unnamed: EPD_C1.2, J3.4
unnamed: EPD_C2.2, J3.5
unnamed: EPD_C6.1, J3.18
unnamed: EPD_C7.1, J3.19
unnamed: EPD_C8.1, J3.20
unnamed: R2_BAT.2, U2.5 (PROG)
unnamed: EPD_C10.1, J3.22
unnamed: R1_BAT.2, U2.1 (STAT)
unnamed: EPD_C12.1, J3.24
unnamed: CHG_LED.C, R1_BAT.1
unnamed: C1_BAT.1, CHG_LED.A, U2.4 (VIN)
unnamed: C_DELAY.1, IC2.5 (CT)
unnamed: D6.1 (CATHODE), R_CAPACITOR.1
PREVGH: D5.1 (K), EPD_C9.1, J3.21
PREVGL: D4.2 (A), EPD_C11.1, J3.23
RESE: J3.3, Q2.2 (S), R2.2
RESE': R2.1, R4.2, SJ1.2
RESET: C10.1, IC2.1 (VOUT), R5.1, RESET_BTN.3, RESET_BTN.4, U3.3 (EN)
RTC_RST: U3.16 (IO18), U5.4 (!RST)
RX: TP2.TP, U3.24 (RXD0/GPIO17)
SCK: D9.2, J2.P5 (CLK), J3.13, R10.1, SCK.TP, U3.6 (IO6), U6.6 (CLK)
SCL: J4.4, R2_PINH.1, U1.4 (SCK), U3.20 (IO22), U4.7 (SCL), U5.16 (SCL)
SDA: J4.3, R1_PINH.1, U1.3 (SDI), U3.19 (IO21), U4.8 (SDA), U5.15 (SDA)
SRC: C5.2, D5.2 (A), L1.1, Q2.3 (D)
SS_SD: D12.2, J2.P2 (CD/DAT3), R13.1, U3.4 (IO4)
TX: TP1.TP, U3.25 (TXD0/GPIO16)
USB_D+: D1.4 (I/O2_2), U3.14 (IO13)
USB_D-: D1.6 (I/O1_2), U3.13 (IO12)
VBAT: C2_BAT.1, Q1.3 (D), U2.3 (VBAT), U4.2 (CELL), U4.3 (VDD), VBAT-PAD.TP
VBUS: C1.1, C2.1, D1.2 (GND), D2.2 (ANODE), PFMF.050.1.2, Q1.1 (G), R1_PWRUSB.2, VBUS-PAD.TP
VRTC: C9.1, C13_SUPERCAP.1, R_CAPACITOR.2, U5.14 (VBAT)
VUSB: J1.A4, J1.A9, J1.B4, J1.B9, PFMF.050.1.1

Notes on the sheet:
USB C connector and ESD protection
Display Type Selector
E-Paper Drive Circuit
E-Paper Display Header
EPD Power
LDO Voltage Regulator
Li-Po Battery Charging Controller
SD Card
ESP32 C6
Battery Charge Level
Environmental Sensor BME688
Voltage Supervisor + Reset and Boot / IO Button
RTC Module DS3231SN
Test Pads
Qwiic / Stemma QT
SPI ESD Protection Lines
External NOR Flash 64MB

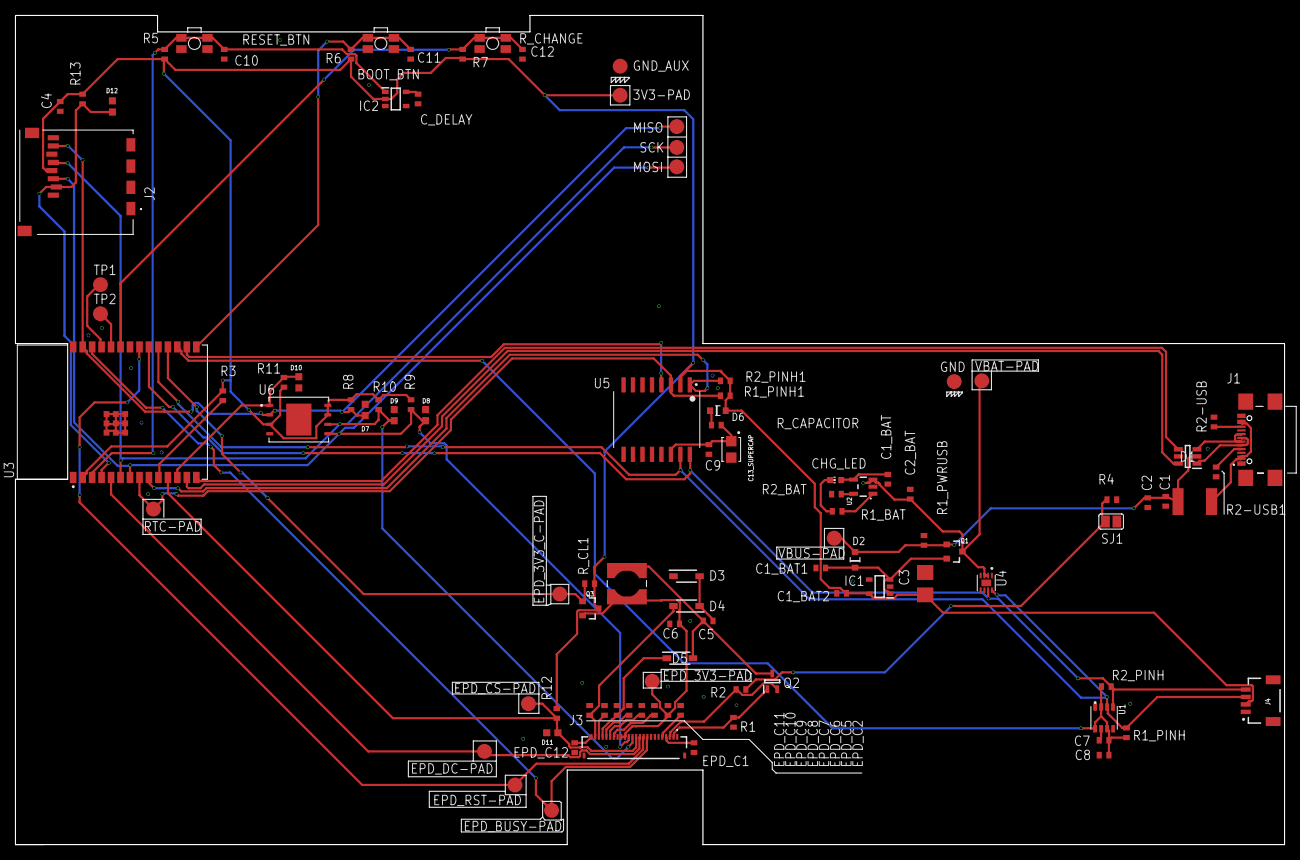
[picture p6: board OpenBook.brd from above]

Board: 2 copper layers, 170.2 x 111.2 mm, 103 parts (0 on the bottom side), 56 nets.

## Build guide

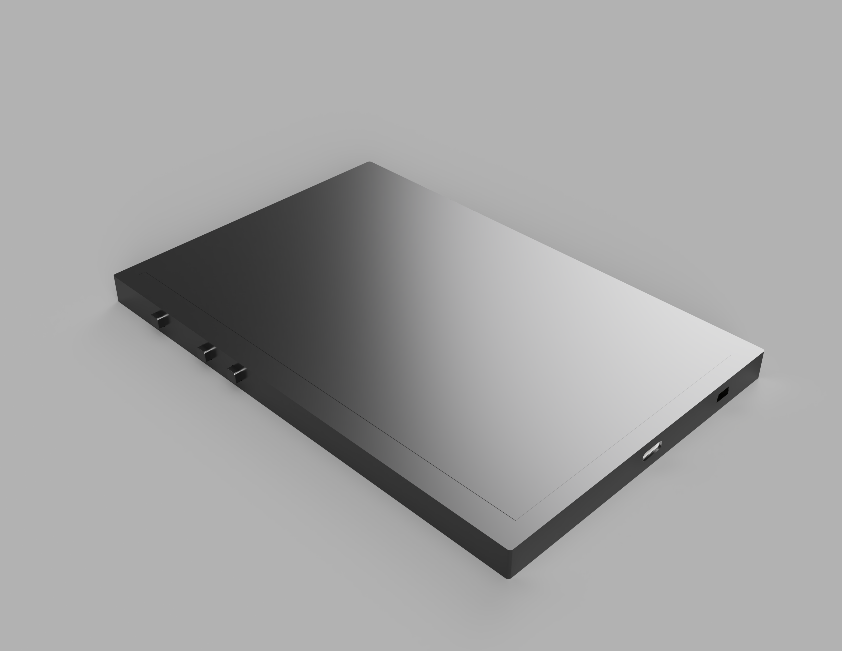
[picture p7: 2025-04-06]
Images/assembled.png

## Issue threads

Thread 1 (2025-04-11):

ERC Warnings

bicoiu, 2025-04-11:
1. Componente fara valoare
S1J, R_CAPACITOR, R7, R6, R5, FRAME1, CHG_LED

2. Pinuri alimentare
U6, U5, U4, U2, U1 (VCC, VBAT, VDD, VIN, etc.) si J4 (3V3, GND)

3. Neturi suprapuse
N$14, N$12

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

Closed 2025-04-14.

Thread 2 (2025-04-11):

Suprapunerea textului pe via-uri si trasee

bicoiu, 2025-04-11:
In anumite zone ale PCB, textul (silkscreen sau reference designators) se suprapune cu via-uri si/sau trasee, ceea ce poate ingreuna citirea si poate duce la probleme de fabricatie.

Closed 2025-04-14.

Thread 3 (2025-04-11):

Trasee de putere trase prin via-uri subtiri

bicoiu, 2025-04-11:
Unele linii de alimentare (de exemplu 3V3 sau VBAT) trec prin via-uri cu diametru/diametru pad insuficient, putand cauza caderi de tensiune mai mari si incalzire.

Closed 2025-04-14.

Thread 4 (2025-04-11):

Footprint inductor nepotrivit

bicoiu, 2025-04-11:
Inductorul ales in schematic nu corespunde cu footprint-ul din PCB (dimensiuni, pad-uri sau forma diferita).

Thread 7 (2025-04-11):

Imbunatatire README

bicoiu, 2025-04-11:
Scopul si Utilizarea Proiectului: O clarificare a scopului dispozitivului si a modului de utilizare.
Arhitectura Hardware: O prezentare detaliata a fiecarui modul (MCU, afisaj, alimentare etc.).
Detalii BoM: Lista completa de componente cu descrieri si link-uri/datasheet-uri.
Mapare Pini / Conexiuni: Un tabel sau o diagrama care sa explice pin-urile si functiile lor.

Closed 2025-04-14.

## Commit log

2025-04-06 Inital Commit
    [BoM_OpenBook v61.csv, OpenBook v27.sch, OpenBook_v61.brd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]
2025-04-14 Fixed some stuff
    +Added via stitching around mcu
    +Fixed inductor footprint with pads
    +Added missing values to resistors
    +Approved redundent erc warnings
    +Fixed unconnected nets
    [OpenBook.brd, OpenBook.sch]
2025-04-14 Updated Screen Fitment
    Updated Pcb Size from the default 1.6mm to the required 1mm for screen to fit properly

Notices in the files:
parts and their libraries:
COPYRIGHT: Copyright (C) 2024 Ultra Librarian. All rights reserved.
